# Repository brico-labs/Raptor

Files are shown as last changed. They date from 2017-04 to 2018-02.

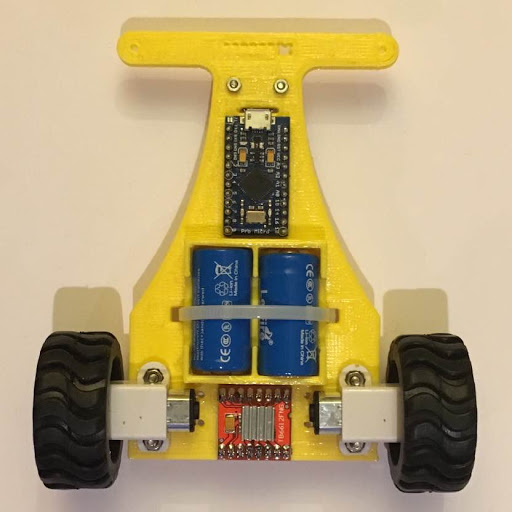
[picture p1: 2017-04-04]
doc/src/img/raptor_mini_up.jpg

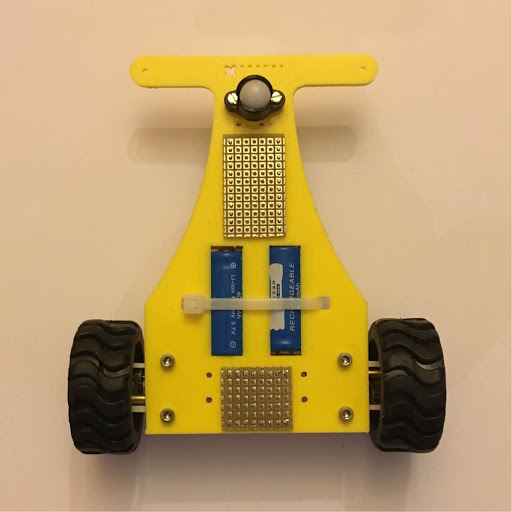
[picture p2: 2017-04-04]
doc/src/img/raptor_mini_down.jpg

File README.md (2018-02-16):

# Raptor

This is the Raptor project repository

A followline robot with N20 motors, 16340 batteries, arduino pro micro and TB6612 or Raspberry Pi Zero.

This repository evolved
from [fstdp/openscad](https://github.com/fstdp/openscad), all openscad
files from the old repo are now on `openscad_misc`directory

# META

This repo
uses [BricoLabs KiCAD](https://github.com/brico-labs/bl_kicad_library)
Library as a submodule.

When cloning this repo you must:

~~~~{bash}
git clone https://github.com/brico-labs/Raptor
cd Raptor
git submodule init
git submodule update
~~~~

or just with one command:

~~~~{bash}
git clone --recursive https://github.com/brico-labs/Raptor
~~~~

# openscad_misc directory

variety of OpenSCAD things from different projects

- SpeedyGonZero, rearwing & ballcaster38 for Raspberry Pi Zero robot

# License MIT

Copyright 2017 Félix Sánchez-Tembleque

Permission is hereby granted, free of charge, to any person obtaining
a copy of this software and associated documentation files (the
"Software"), to deal in the Software without restriction, including
without limitation the rights to use, copy, modify, merge, publish,
distribute, sublicense, and/or sell copies of the Software, and to
permit persons to whom the Software is furnished to do so, subject to
the following conditions:

The above copyright notice and this permission notice shall be
included in all copies or substantial portions of the Software.

THE SOFTWARE IS PROVIDED "AS IS", WITHOUT WARRANTY OF ANY KIND,
EXPRESS OR IMPLIED, INCLUDING BUT NOT LIMITED TO THE WARRANTIES OF
MERCHANTABILITY, FITNESS FOR A PARTICULAR PURPOSE AND
NONINFRINGEMENT. IN NO EVENT SHALL THE AUTHORS OR COPYRIGHT HOLDERS BE
LIABLE FOR ANY CLAIM, DAMAGES OR OTHER LIABILITY, WHETHER IN AN ACTION
OF CONTRACT, TORT OR OTHERWISE, ARISING FROM, OUT OF OR IN CONNECTION
WITH THE SOFTWARE OR THE USE OR OTHER DEALINGS IN THE SOFTWARE.

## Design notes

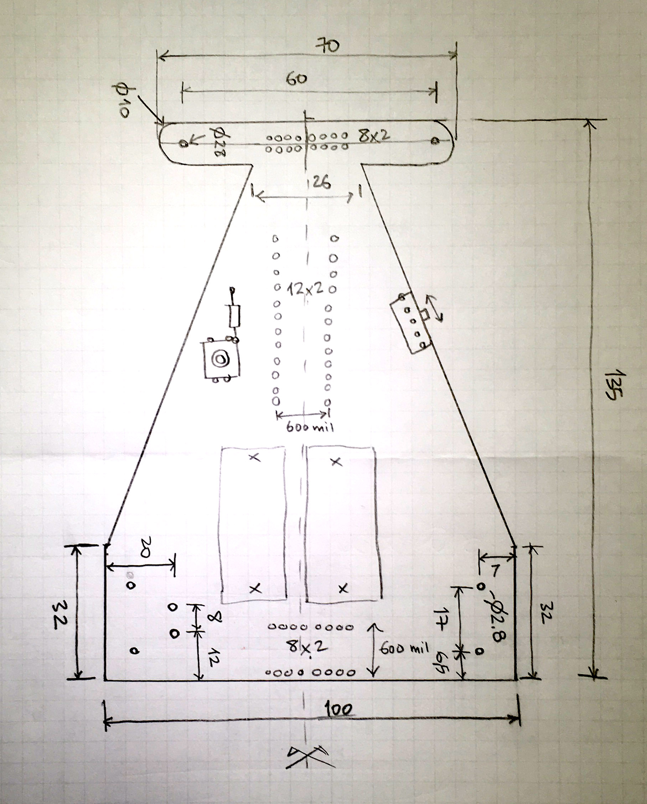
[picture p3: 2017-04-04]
doc/src/img/raptor_croquis.JPG

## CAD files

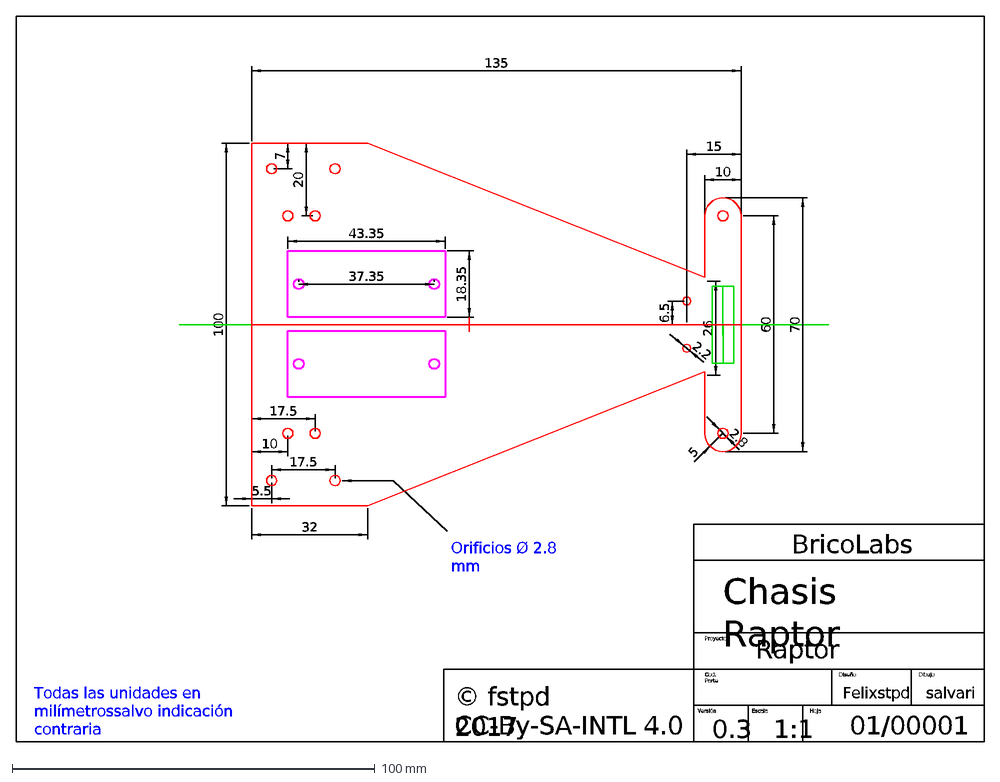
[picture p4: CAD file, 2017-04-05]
librecad/Raptor_PCB.dxf
BricoLabs
Versión
Escala
Hoja
Cod. Parte
Proyecto
Dibujo
1:1
salvari
01/00001
Raptor
Chasis Raptor
CC-By-SA-INTL 4.0
© fstpd 2017
100
32
10
60
2.8
5
Diseño
Felixstpd
Todas las unidades en milímetros salvo indicación contraria
135
70
7
20
5.5
17.5
Orificios Ø 2.8 mm
26
15
6.5
2.2
18.35
43.35
37.35
0.3

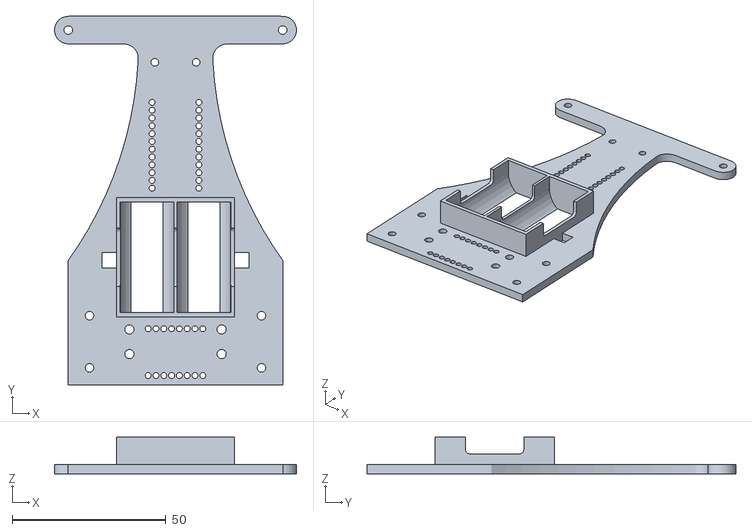
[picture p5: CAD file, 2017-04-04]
openscad/raptor_mini.stl
78.8 x 120.0 x 12.0

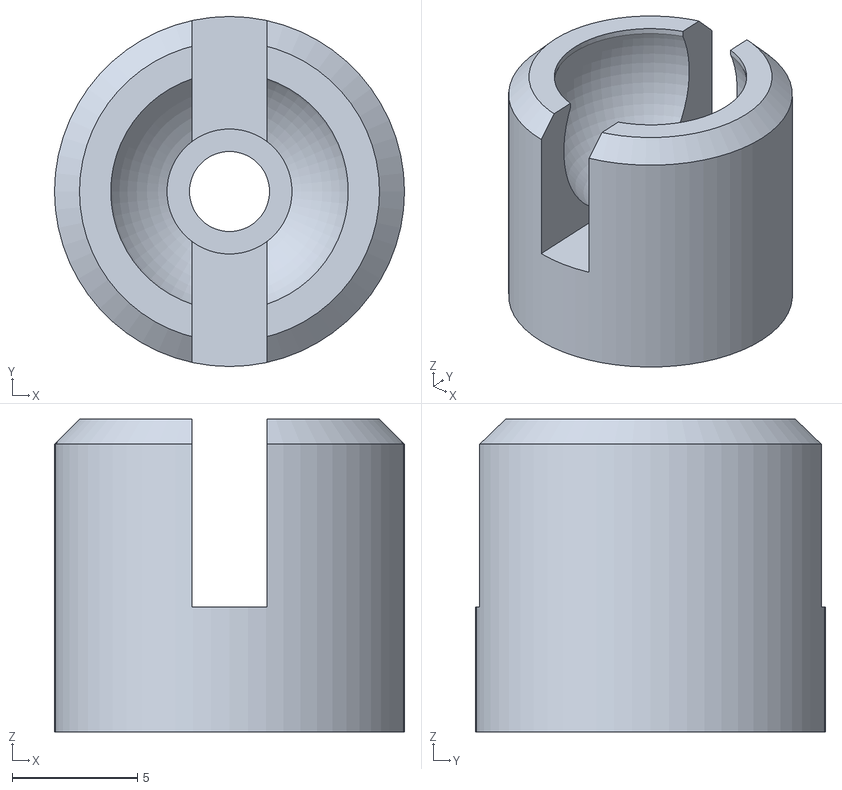
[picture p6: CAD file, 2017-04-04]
openscad_misc/ballcaster38.stl
14.0 x 14.0 x 12.5

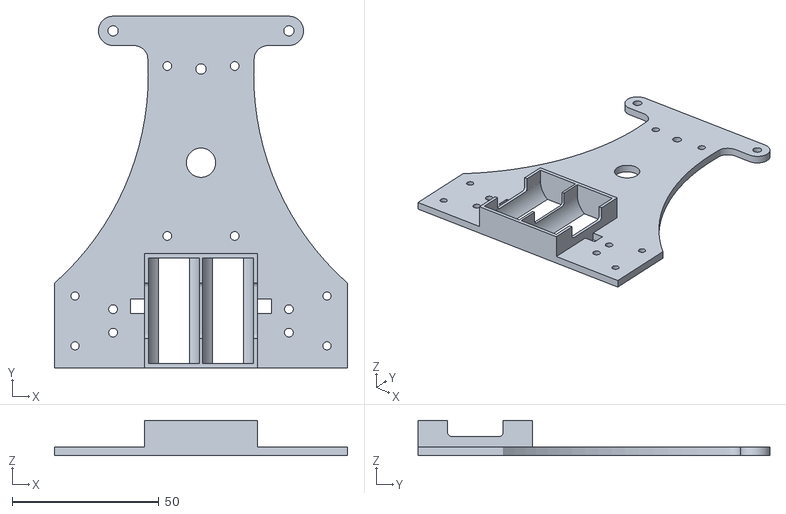
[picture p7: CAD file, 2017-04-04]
openscad/raptor_zero.stl
100.0 x 120.0 x 12.0

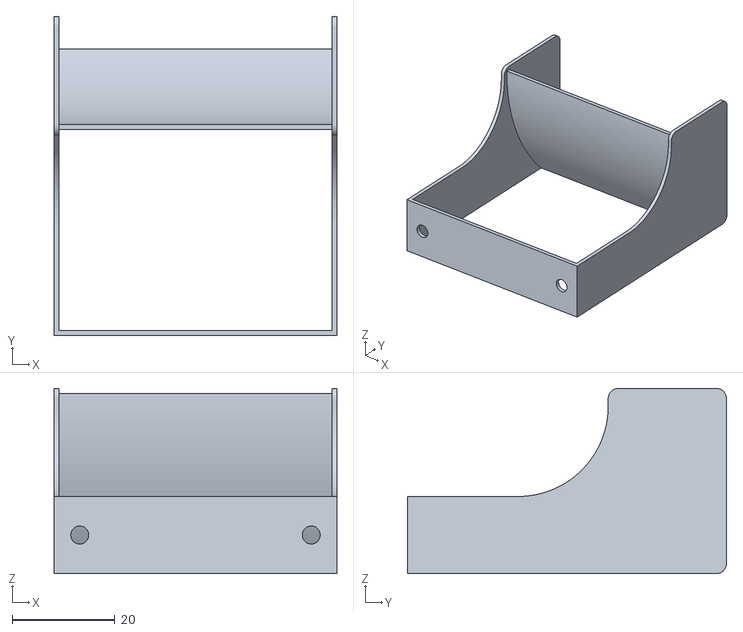
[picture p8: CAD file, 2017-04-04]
openscad_misc/rearwing.stl
55.0 x 62.0 x 36.0

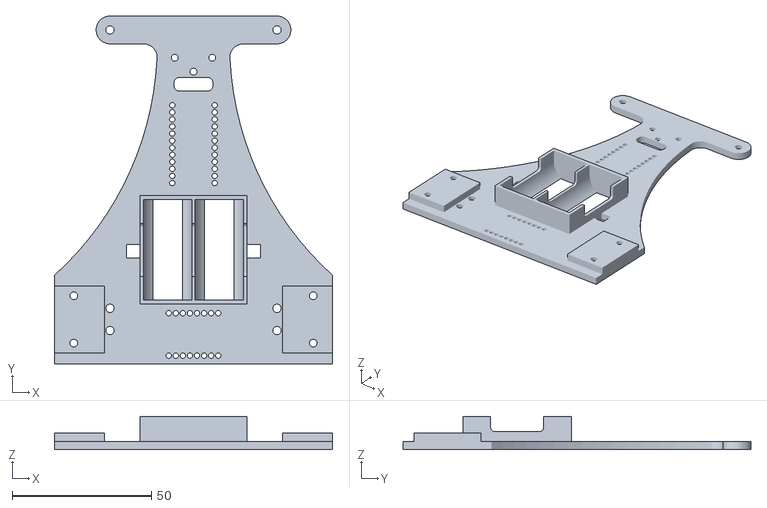
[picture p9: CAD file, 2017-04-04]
openscad/raptor.stl
100.0 x 125.0 x 12.0

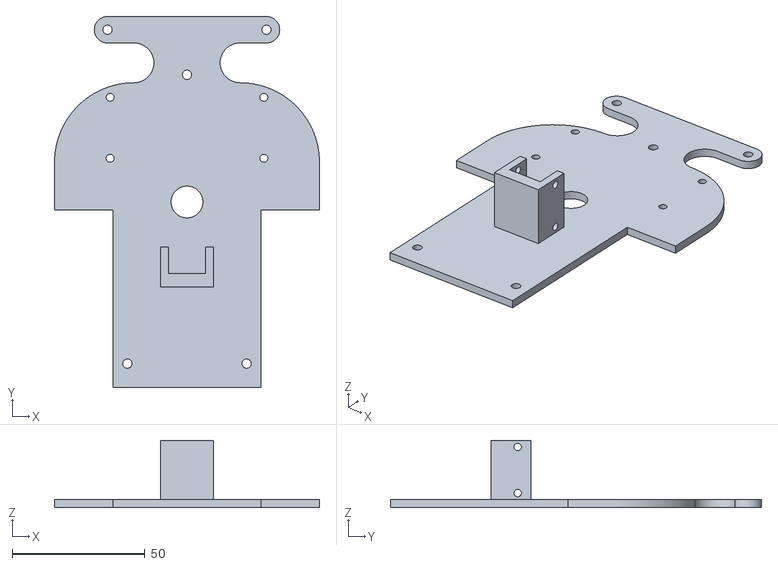
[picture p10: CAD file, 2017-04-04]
openscad_misc/speedygonzero.stl
100.0 x 140.0 x 25.4

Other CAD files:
openscad_misc/speedy_yellow_motor.scad
openscad/raptor.scad
openscad/raptor_AAA.scad
openscad/raptor_mini.scad
openscad/raptor_zero.scad
openscad_misc/ballcaster38.scad
openscad_misc/bat16340holder.scad
openscad_misc/rearwing.scad
openscad_misc/rearwing_low.scad
openscad_misc/speedygonzero_N20.scad

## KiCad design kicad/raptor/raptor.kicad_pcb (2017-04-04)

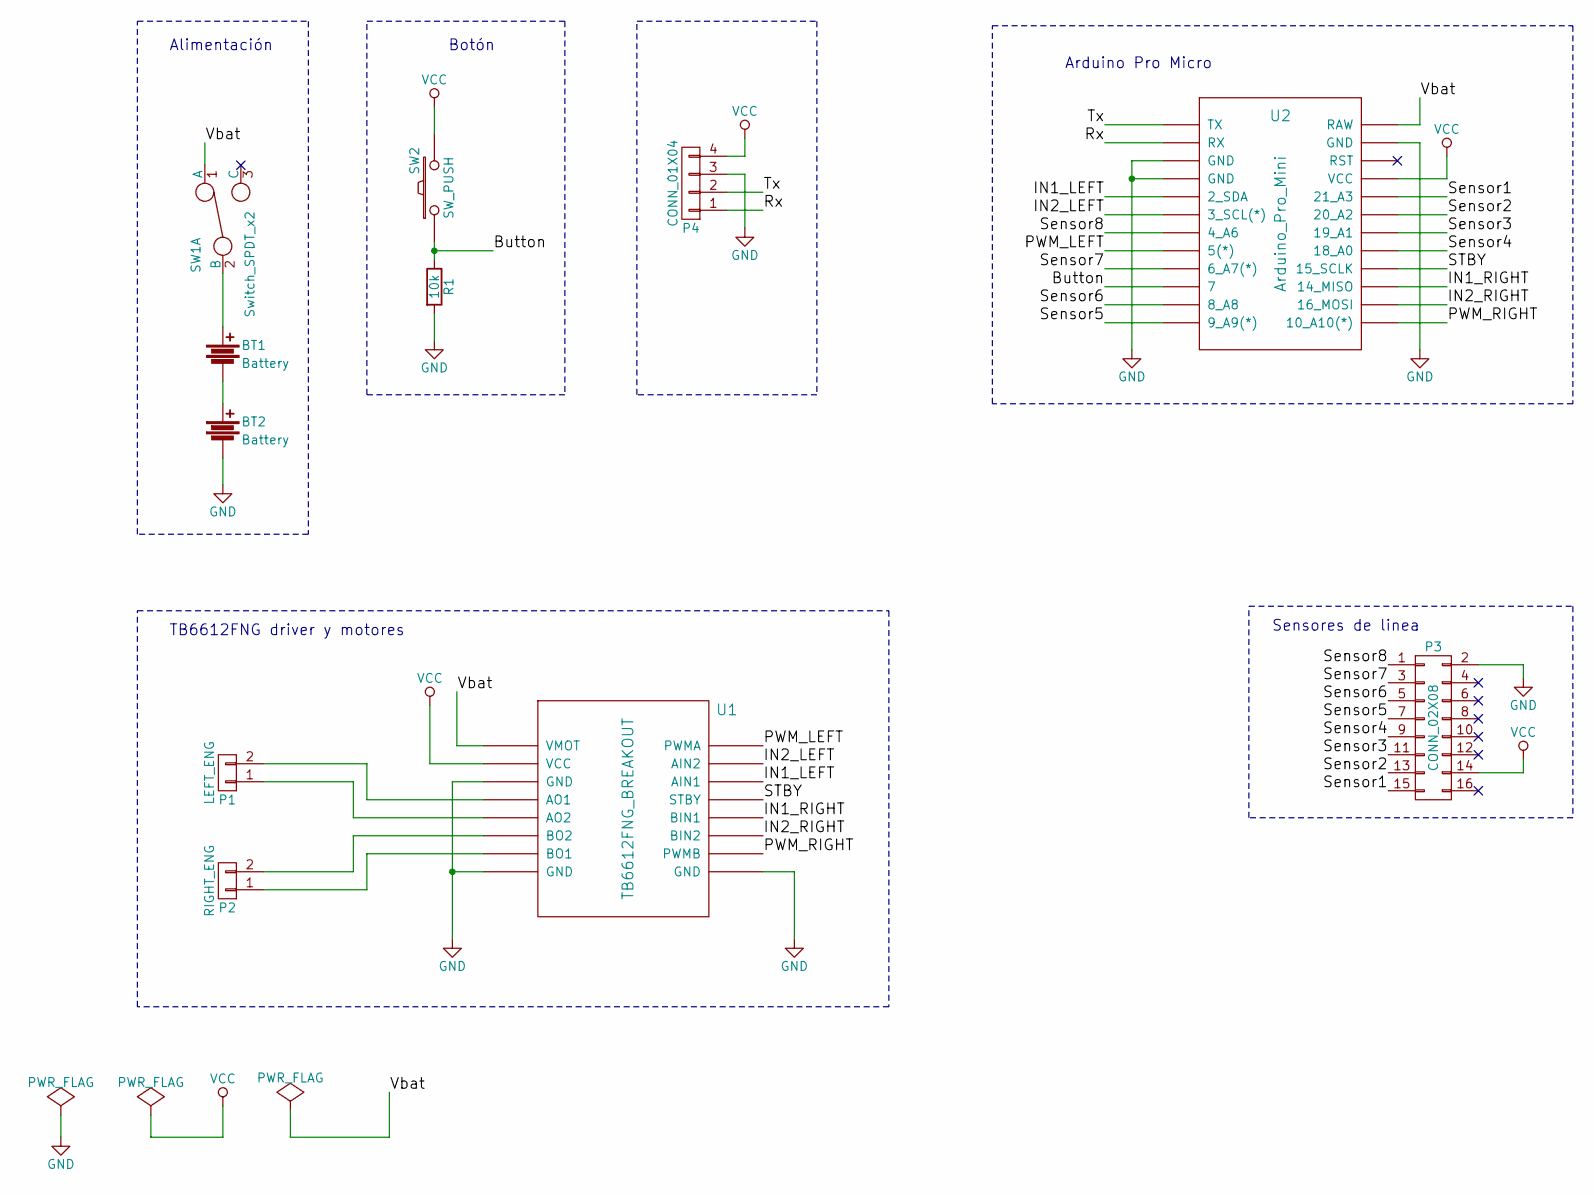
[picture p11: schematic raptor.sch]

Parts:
BT1, BT2: Battery; Battery_16340
P1: LEFT_ENG; Motor_raptor
P2: RIGHT_ENG; Motor_raptor
P3: CONN_02X08; Socket_Strip_Straight_2x08
P4: CONN_01X04; Socket_Strip_Straight_1x04
R1: 10k; Resistor_Horizontal_RM7mm
SW1: Switch_SPDT_x2; SW_Micro_SPST
SW2: SW_PUSH; SW_PUSH-12mm
U1: TB6612FNG_BREAKOUT; DIP-16_600
U2: Arduino_Pro_Mini; DIP-24_600

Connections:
/Button: R1.1, SW2.1, U2.10 (7)
/IN1_LEFT: U1.14 (AIN1), U2.5 (2_SDA)
/IN1_RIGHT: U1.12 (BIN1), U2.15 (14_MISO)
/IN2_LEFT: U1.15 (AIN2), U2.6 (3_SCL(*))
/IN2_RIGHT: U1.11 (BIN2), U2.14 (16_MOSI)
/PWM_LEFT: U1.16 (PWMA), U2.8 (5(*))
/PWM_RIGHT: U1.10 (PWMB), U2.13 (10_A10(*))
/Rx: P4.1, U2.2 (RX)
/STBY: U1.13 (STBY), U2.16 (15_SCLK)
/Sensor1: P3.15, U2.20 (21_A3)
/Sensor2: P3.13, U2.19 (20_A2)
/Sensor3: P3.11, U2.18 (19_A1)
/Sensor4: P3.9, U2.17 (18_A0)
/Sensor5: P3.7, U2.12 (9_A9(*))
/Sensor6: P3.5, U2.11 (8_A8)
/Sensor7: P3.3, U2.9 (6_A7(*))
/Sensor8: P3.1, U2.7 (4_A6)
/Tx: P4.2, U2.1 (TX)
/Vbat: SW1.1 (A), U1.1 (VMOT), U2.24 (RAW)
GND: BT2.2, P3.2, P4.3, R1.2, U1.3 (GND), U1.8 (GND), U1.9 (GND), U2.3 (GND), U2.4 (GND), U2.23 (GND)
unnamed: BT1.1, SW1.2 (B)
unnamed: BT1.2, BT2.1
unnamed: P1.1, U1.5 (AO2)
unnamed: P1.2, U1.4 (AO1)
unnamed: P2.1, U1.7 (BO1)
unnamed: P2.2, U1.6 (BO2)
VCC: P3.14, P4.4, SW2.2, U1.2 (VCC), U2.21 (VCC)

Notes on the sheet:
Alimentación
Botón
TB6612FNG driver y motores
Sensores de linea
Arduino Pro Micro

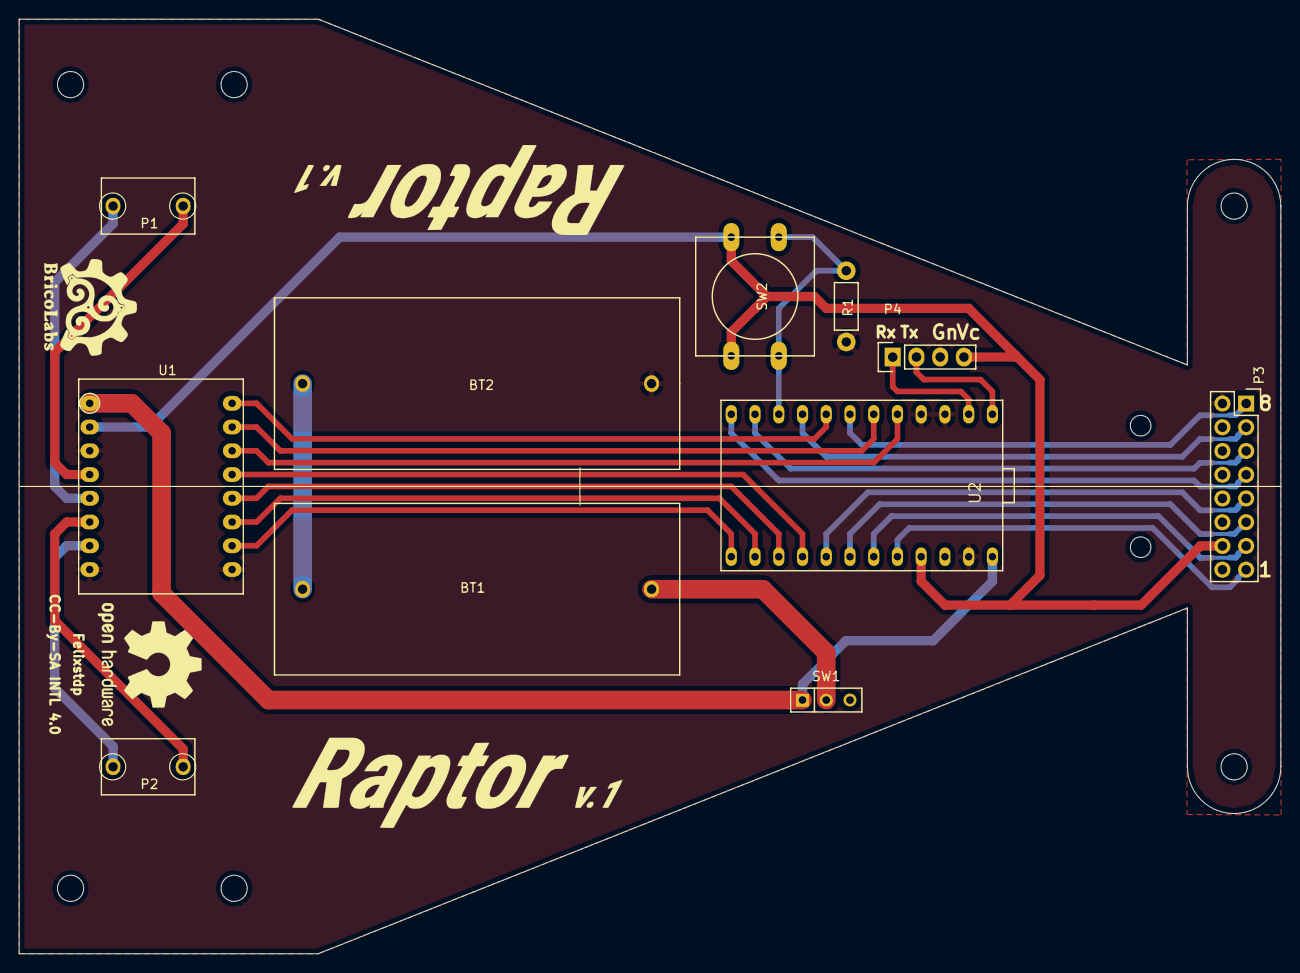
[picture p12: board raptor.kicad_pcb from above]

Board: 2 copper layers, 135.0 x 100.0 mm, 11 parts (0 on the bottom side), 27 nets.

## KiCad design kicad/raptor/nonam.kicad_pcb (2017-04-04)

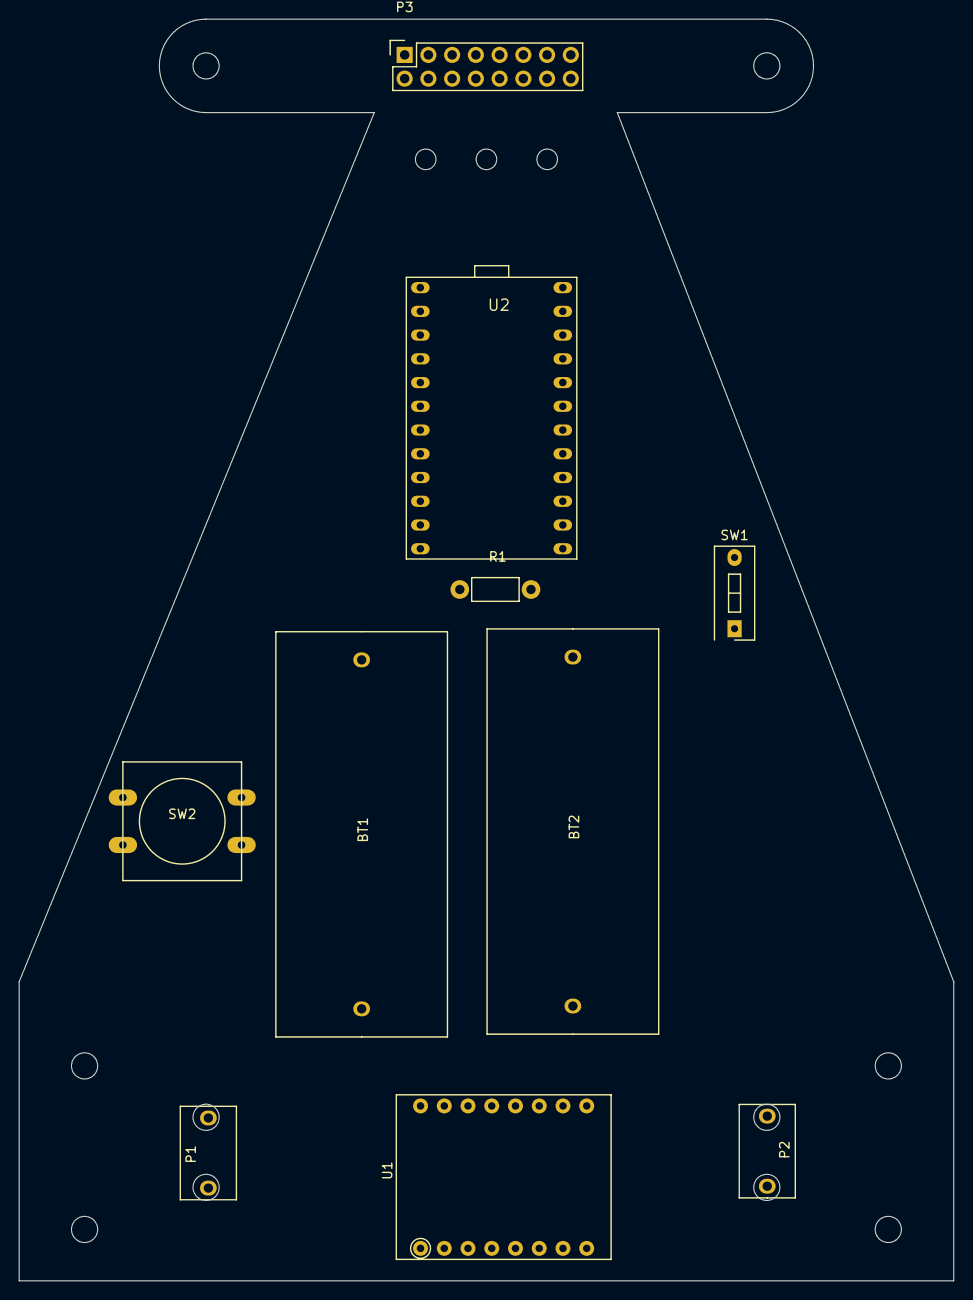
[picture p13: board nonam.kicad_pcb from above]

Board: 2 copper layers, 100.0 x 135.0 mm, 10 parts (0 on the bottom side), 24 nets, no tracks yet.

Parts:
BT1, BT2: Battery; Battery_16340
P1: LEFT_ENG; Motor_raptor
P2: RIGHT_ENG; Motor_raptor
P3: CONN_02X08; Socket_Strip_Straight_2x08
R1: 10k; Resistor_Horizontal_RM7mm
SW1: SPST; SW_DIP_x1_Slide
SW2: SW_PUSH; SW_PUSH-12mm
U1: TB6612FNG_BREAKOUT; DIP-16_600
U2: Arduino_Pro_Mini; DIP-24_600

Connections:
/Button: R1.1, SW2.1, U2.10
/IN1_LEFT: U1.14, U2.5
/IN1_RIGHT: U1.12, U2.15
/IN2_LEFT: U1.15, U2.6
/IN2_RIGHT: U1.11, U2.14
/PWM_LEFT: U1.16, U2.8
/PWM_RIGHT: U1.10, U2.13
/STBY: U1.13, U2.16
/Sensor1: P3.16, U2.17
/Sensor2: P3.14, U2.18
/Sensor3: P3.12, U2.19
/Sensor4: P3.10, U2.20
/Sensor5: P3.8, U2.7
/Sensor6: P3.6, U2.9
/Sensor7: P3.4, U2.11
/Sensor8: P3.2, U2.12
GND: BT2.2, P3.1, R1.2, U1.1, U1.8, U1.9, U2.3, U2.4, U2.23
unnamed: BT1.1, SW1.1
unnamed: BT1.2, BT2.1
unnamed: P1.1, U1.4
unnamed: P1.2, U1.3
unnamed: P2.1, U1.6
unnamed: P2.2, U1.5
VCC: P3.13, SW1.2, SW2.2, U1.2, U2.24

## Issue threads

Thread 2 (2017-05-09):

Protection diode

salvari, 2017-05-09:
To prevent mistakes with batteries

MiloBarral, 2017-05-09:
Hahaha.

4m1g0, 2017-05-10:
AHAHAHAHA

Shiul93, 2017-05-10:
HUEHUEHUEHEUHEU

Scraw, 2017-05-10:
To prevent burn Arduino you mean...

rafacouto, 2017-05-11:
cp -r /github/escornabot/electronics/powerprotection /github/raptor/powerprotection # ;)

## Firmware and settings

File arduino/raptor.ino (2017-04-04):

// programa para el robot Raptor siguelíneas. work in progress

#include <Wire.h>
#define uchar unsigned char
uchar t;


int STBY = 15; //standby

//Motor A
int PWMA = 5; //Speed control 
int AIN1 = 2; //Direction
int AIN2 = 3; //Direction

//Motor B
int PWMB = 10; //Speed control
int BIN1 = 14; //Direction
int BIN2 = 16; //Direction

uchar data[16];
void setup()
{
  Wire.begin();        // join i2c bus (address optional for master)
  Serial.begin(9600);  // start serial for output
  t = 0;
}
void loop()
{
  Wire.requestFrom(9, 16);    // request 16 bytes from slave device #9
  while (Wire.available())   // slave may send less than requested
  {
    data[t] = Wire.read(); // receive a byte as character
    if (t < 15)
      t++;
    else
      t = 0;
  }

}

//motor A connected between A01 and A02
//motor B connected between B01 and B02


void drive(int speedl, int speedr)
{
  digitalWrite(STBY, HIGH); //disable standby

  if (speedl>0)
  {
    digitalWrite(AIN1, LOW); // change high for low if wheel doesnt spin forward
    digitalWrite(AIN2, HIGH);
    analogWrite(PWMA, speedl);
  } else {
    digitalWrite(AIN1, HIGH);
    digitalWrite(AIN2, LOW);
    analogWrite(PWMA, -speedl);
  }  
  if (speedr>0)
  {
    digitalWrite(BIN1, LOW); // change high for low if wheel doesnt spin forward
    digitalWrite(BIN2, HIGH);
    analogWrite(PWMB, speedr);
  } else {
    digitalWrite(BIN1, HIGH);
    digitalWrite(BIN2, LOW);
    analogWrite(PWMB, -speedr);
  }  
}

void stop(){
//enable standby  
  digitalWrite(STBY, LOW); 
}

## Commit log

2017-04-04 Root directory renamed Cleaning up root directory Created doc directory
    [ballcaster38.scad, ballcaster38.stl, bat16340holder.scad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]
2017-04-04 Added BricoLabs KiCAD library as submodule on Raptor KiCAD project
    [nonam.kicad_pcb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]
2017-04-05 Added dxf LibreCAD file for Raptor PCB
    [Raptor_PCB.dxf]
2017-09-24 Some cleaning
    [Raptor_PCB.dxf]
